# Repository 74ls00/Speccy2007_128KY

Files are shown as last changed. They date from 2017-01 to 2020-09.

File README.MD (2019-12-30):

# Speccy 2007 128K AY PAL SCART 2017

За основу взята единственная на тот момент полная схема 128к от Ljubitel, архив его проекта тут https://github.com/74ls00/Speccy2007_by_Ljubitel

Добавлен кодер PAL и разъём SCART.

Проект в процессе тестирования

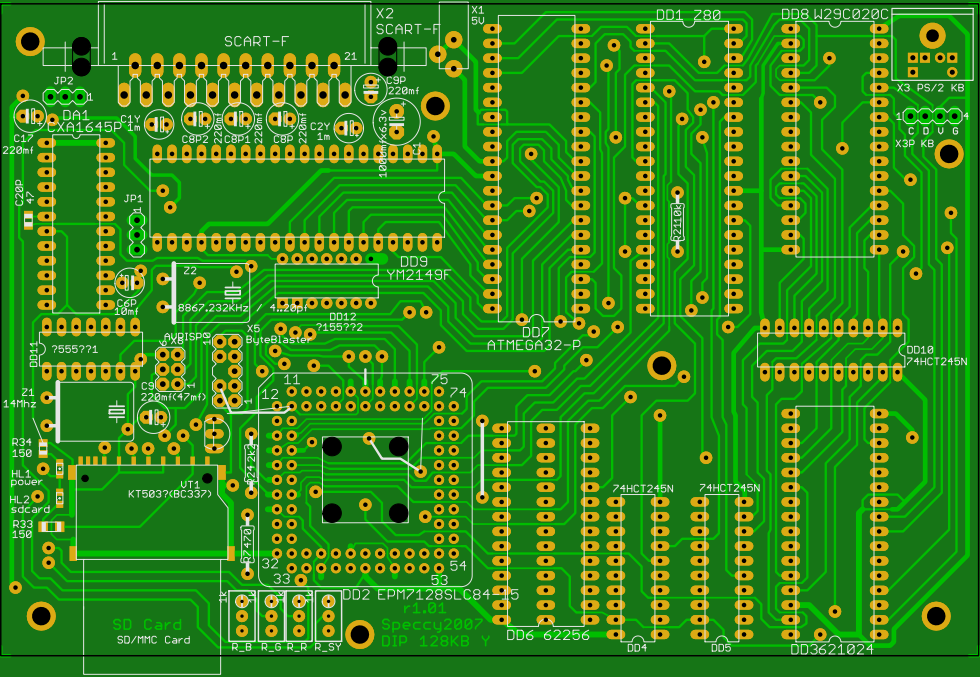
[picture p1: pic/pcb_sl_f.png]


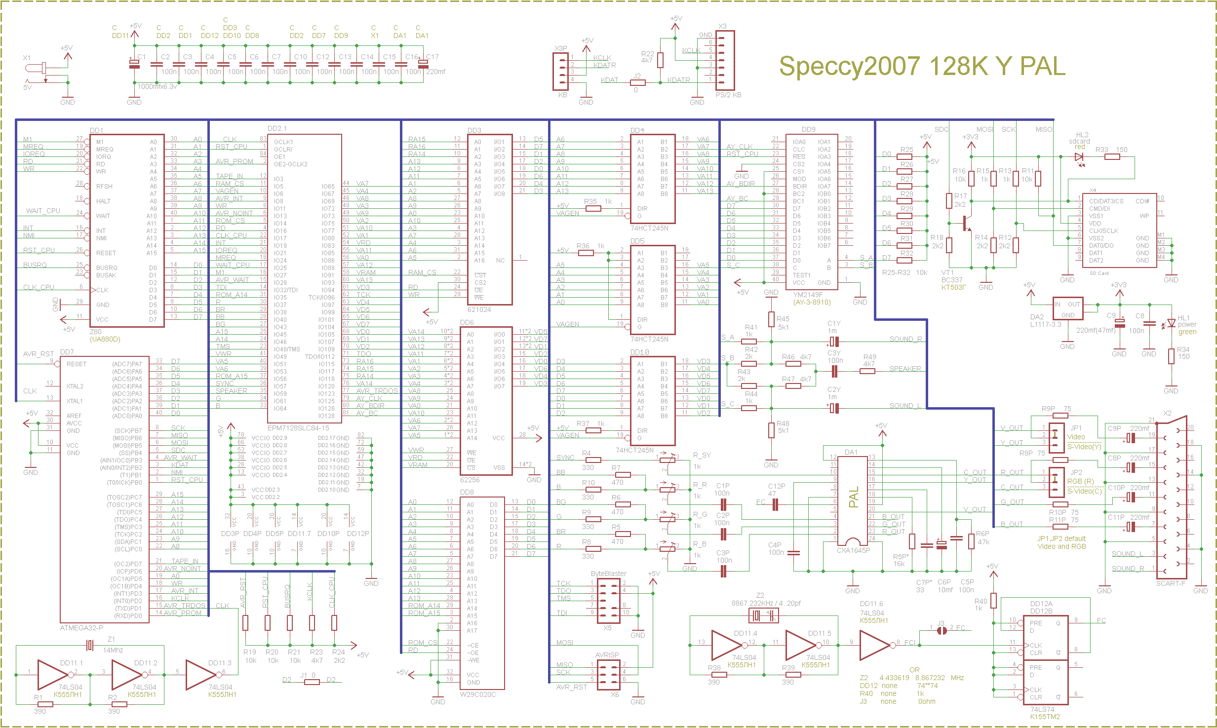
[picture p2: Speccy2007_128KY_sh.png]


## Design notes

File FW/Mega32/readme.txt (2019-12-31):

speccy2007_v106r4_(128+AY+trdos)_src.7z
http://zx-pk.ru/threads/10316-speccy2007-v1-06-(128-ay-trdos).html

Список клавиш
https://zx-pk.ru/threads/12027-speccy2007-sborka-i-naladka.html?p=295229&viewfull=1#post295229

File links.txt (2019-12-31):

Speccy2007 - сборка и наладка
https://zx-pk.ru/threads/12027-speccy2007-sborka-i-naladka.html

Speccy2007 v1.06 (128 + AY + TRDOS)
https://zx-pk.ru/threads/10316-speccy2007-v1-06-(128-ay-trdos).html

Speccy2007 v1.00
https://zx-pk.ru/threads/6679-speccy2007-v1-00.html

Speccy2007 v2.00
теоретическая тема заброшена в 2009
https://zx-pk.ru/threads/9927-speccy2007-v2-00.html

Ссылки на этот гит.
Мой проект 2017
https://github.com/74ls00/Speccy2007_128KY
Авторский проект 2010
https://github.com/74ls00/Speccy2007_by_Ljubitel

Дальнейшее наблюдение за темой "Speccy2007 v1.06 (128 + AY + TRDOS)" начато в 2019.
Вариант с одной микросхемой ОЗУ с.33
прошивка к нему с.34
Модифицированая прошивка с.35, исправление с.36, с.42, (43)

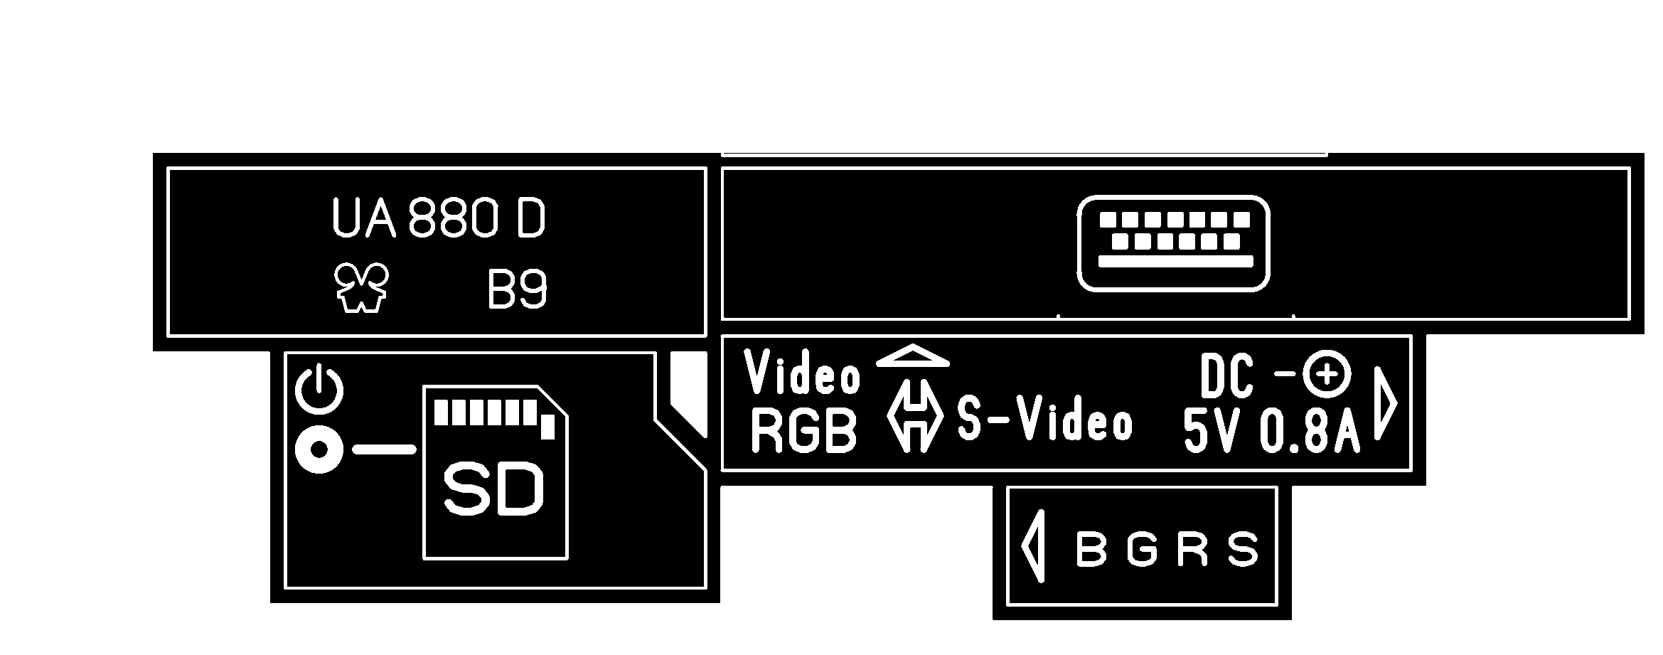
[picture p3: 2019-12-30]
sticker/sticker.png

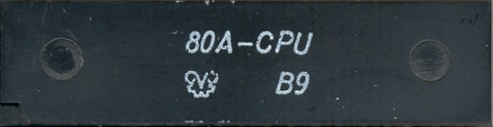
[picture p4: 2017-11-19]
sticker/mme_80a_cpu_b9_cr.bmp

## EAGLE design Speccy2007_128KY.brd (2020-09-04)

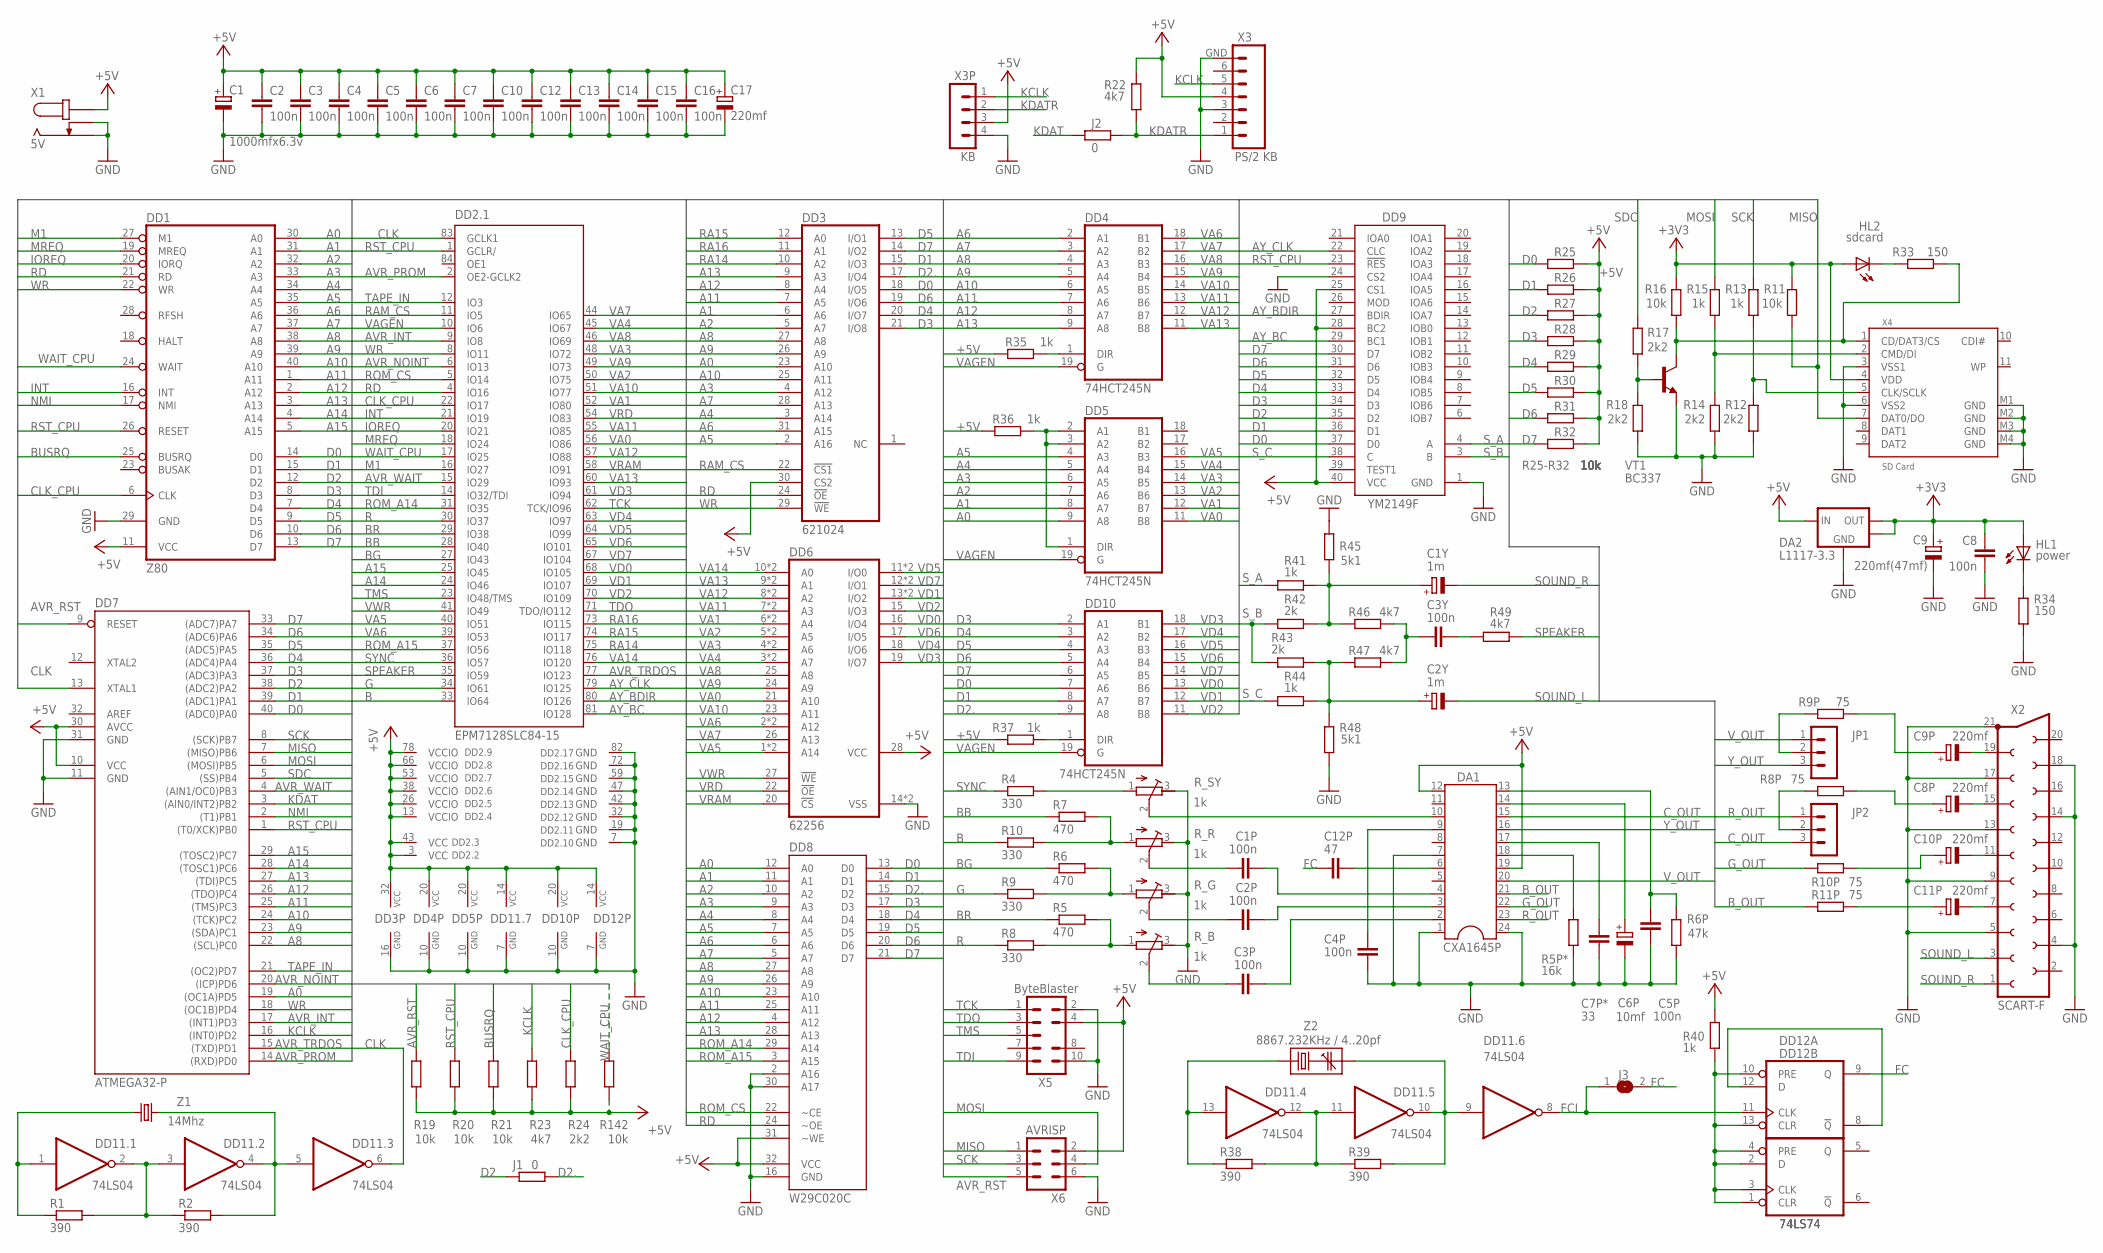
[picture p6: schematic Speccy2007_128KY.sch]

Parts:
C1: 1000mfx6.3v; E3,5-8
C1P, C2, C2P, C3, C3P, C3Y, C4P, C5, C7, C8, C10, C12, C13, C14, C15, C16: 100n; C0805
C1Y, C2Y: 1m; E2,5-5
C4, C5P, C6: 100n; C1206
C6P: 10mf; E2,5-5
C7P*: 33; C1206
C8P, C9P, C10P, C11P, C17: 220mf; E2,5-6
C9: 220mf(47mf); E2,5-6
C12P: 47; C0805
DA1: CXA1645P; DIL24-4
DA2: L1117-3.3; SOT-223
DD1: Z80; DIL40
DD2: EPM7128SLC84-15; PGA-84-B
DD3: 621024; DIL32
DD4, DD5, DD10: 74HCT245N; DIL20
DD6: 62256; DIL28+6
DD7: ATMEGA32-P; DIL40
DD8: W29C020C; DIL32
DD9: YM2149F; DIL40
DD11: 74LS04; DIL14
DD12: 74LS74; DIL14O
HL1: power; SML0805
HL2: sdcard; SML0805
J1: 0; M1206
J2: 0; R1206
J3: SJ
JP1, JP2: MA03-1
R1, R2, R38, R39: 390; R0805
R4, R8, R9, R10: 330; R0805
R5: 470; R0805
R5P*: 16k; M1206
R6: 470; R1206
R6P: 47k; R0805
R7: 470; 0207/10
R8P, R9P, R10P, R11P: 75; R1206
R11, R16, R20, R25, R27, R28, R29, R30, R31, R32: 10k; R0805
R12: 2k2; R1206
R13, R15, R35, R36, R37, R40, R41: 1k; R0805
R14, R17, R18: 2k2; R0805
R19, R26: 10k; M0805
R21, R142: 10k; 0207/10
R22, R47, R49: 4k7; R0805
R23, R46: 4k7; R1206
R24: 2k2; 0207/10
R33: 150; R1206
R34: 150; R0805
R42, R43: 2k; R0805
R44: 1k; R1206
R45: 5k1; R1206
R48: 5k1; R0805
R_B: 1k; RTRIM3296W
R_G: 1k; RTRIM3296W
R_R: 1k; RTRIM3296W
R_SY: 1k; RTRIM3296W
VT1: BC337; TO92-CBE
X1: 5V; POWER3.5
X2: SCART-F
X3: PS/2 KB; MINI-DIN6
X3P: KB; MA04-1
X4: SD Card; SDCMF-10915W010
X5: ByteBlaster; MA05-2
X6: AVRISP; MA03-2
Z1: 14Mhz; HC49U-H
Z2: 8867.232KHz / 4..20pf; HC49U-H

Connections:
+3V3: C8.1, C9.+, DA2.2 (OUT), DA2.4 (OUT'), HL1.A, HL2.A, R11.2, R16.2, X4.4 (VDD)
+5V: C1.+, C2.1, C3.1, C4.1, C5.1, C6.1, C7.1, C10.1, C12.1, C13.1, C14.1, C15.1, C16.1, C17.+, DA1.12, DA1.19, DA2.3 (IN), DD1.11 (VCC), DD2.3 (VCC), DD2.13 (VCCIO), DD2.26 (VCCIO), DD2.38 (VCCIO), DD2.43 (VCC), DD2.53 (VCCIO), DD2.66 (VCCIO), DD2.78 (VCCIO), DD3.30 (CS2), DD3.32 (VCC), DD4.20 (VCC), DD5.20 (VCC), DD6.28 (VCC), DD7.10 (VCC), DD7.30 (AVCC), DD8.31 (~WE), DD8.32 (VCC), DD9.25 (CS1), DD9.28 (BC2), DD9.40 (VCC), DD10.20 (VCC), DD11.14 (VCC), DD12.14 (VCC), R19.1, R20.1, R21.1, R22.2, R23.1, R24.1, R25.2, R26.2, R27.2, R28.2, R29.2, R30.2, R31.2, R32.2, R35.2, R36.2, R37.2, R40.2, R142.1, X1.P$1 (1), X3.4, X3P.3, X5.4, X6.2
A0: DD1.30 (A0), DD3.23 (A10), DD5.9 (A8), DD7.19 ((OC1A)PD5), DD8.12 (A0)
A1: DD1.31 (A1), DD3.6 (A6), DD5.8 (A7), DD8.11 (A1)
A2: DD1.32 (A2), DD3.5 (A7), DD5.7 (A6), DD8.10 (A2)
A3: DD1.33 (A3), DD3.4 (A12), DD5.6 (A5), DD8.9 (A3)
A4: DD1.34 (A4), DD3.3 (A14), DD5.5 (A4), DD8.8 (A4)
A5: DD1.35 (A5), DD3.2 (A16), DD5.4 (A3), DD8.7 (A5)
A6: DD1.36 (A6), DD3.31 (A15), DD4.2 (A1), DD8.6 (A6)
A7: DD1.37 (A7), DD3.28 (A13), DD4.3 (A2), DD8.5 (A7)
A8: DD1.38 (A8), DD3.27 (A8), DD4.4 (A3), DD7.22 ((SCL)PC0), DD8.27 (A8)
A9: DD1.39 (A9), DD3.26 (A9), DD4.5 (A4), DD7.23 ((SDA)PC1), DD8.26 (A9)
A10: DD1.40 (A10), DD3.25 (A11), DD4.6 (A5), DD7.24 ((TCK)PC2), DD8.23 (A10)
A11: DD1.1 (A11), DD3.7 (A5), DD4.7 (A6), DD7.25 ((TMS)PC3), DD8.25 (A11)
A12: DD1.2 (A12), DD3.8 (A4), DD4.8 (A7), DD7.26 ((TDO)PC4), DD8.4 (A12)
A13: DD1.3 (A13), DD3.9 (A3), DD4.9 (A8), DD7.27 ((TDI)PC5), DD8.28 (A13)
A14: DD1.4 (A14), DD2.24 (IO46), DD7.28 ((TOSC1)PC6)
A15: DD1.5 (A15), DD2.25 (IO45), DD7.29 ((TOSC2)PC7)
AVR_INT: DD2.9 (IO8), DD7.17 ((INT1)PD3)
AVR_NOINT: DD2.6 (IO13), DD7.20 ((ICP)PD6)
AVR_PROM: DD2.2 (OE2-GCLK2), DD7.14 ((RXD)PD0)
AVR_RST: DD7.9 (RESET), R19.2, X6.5
AVR_TRDOS: DD2.77 (IO123), DD7.15 ((TXD)PD1)
AVR_WAIT: DD2.15 (IO29), DD7.4 ((AIN1/OC0)PB3)
AY_BC: DD2.81 (IO128), DD9.29 (BC1)
AY_BDIR: DD2.80 (IO126), DD9.27 (BDIR)
AY_CLK: DD2.79 (IO125), DD9.22 (CLC)
B: DD2.33 (IO64), R10.1
BB: DD2.28 (IO40), R7.1
BG: DD2.27 (IO43), R6.1
BR: DD2.29 (IO38), R5.1
BUSRQ: DD1.25 (BUSRQ), R21.2
B_OUT: DA1.21, R11P.1
CDDAT3: R16.1, R33.1, VT1.C, X4.1 (CD/DAT3/CS)
CLK: DD2.83 (GCLK1), DD7.13 (XTAL1), DD11.6 (O)
CLK_CPU: DD1.6 (CLK), DD2.22 (IO17), R24.2
C_OUT: DA1.15, JP2.3
D0: DD1.14 (D0), DD3.18 (I/O5), DD7.40 ((ADC0)PA0), DD8.13 (D0), DD9.37 (D0), DD10.7 (A6), R25.1
D1: DD1.15 (D1), DD3.15 (I/O3), DD7.39 ((ADC1)PA1), DD8.14 (D1), DD9.36 (D1), DD10.8 (A7), R26.1
D2: DD1.12 (D2), DD7.38 ((ADC2)PA2), DD9.35 (D2), J1.1, R27.1
D2.: DD3.17 (I/O4), DD8.15 (D2), DD10.9 (A8), J1.2
D3: DD1.8 (D3), DD3.21 (I/O8), DD7.37 ((ADC3)PA3), DD8.17 (D3), DD9.34 (D3), DD10.2 (A1), R28.1
D4: DD1.7 (D4), DD3.20 (I/O7), DD7.36 ((ADC4)PA4), DD8.18 (D4), DD9.33 (D4), DD10.3 (A2), R29.1
D5: DD1.9 (D5), DD3.13 (I/O1), DD7.35 ((ADC5)PA5), DD8.19 (D5), DD9.32 (D5), DD10.4 (A3), R30.1
D6: DD1.10 (D6), DD3.19 (I/O6), DD7.34 ((ADC6)PA6), DD8.20 (D6), DD9.31 (D6), DD10.5 (A4), R31.1
D7: DD1.13 (D7), DD3.14 (I/O2), DD7.33 ((ADC7)PA7), DD8.21 (D7), DD9.30 (D7), DD10.6 (A5), R32.1
FC: C12P.1, DD12.9 (Q), J3.2
FCI: DD11.8 (O), DD12.11 (CLK), J3.1
G: DD2.34 (IO61), R9.1
GND: C1.-, C2.2, C3.2, C4.2, C4P.1, C5.2, C5P.1, C6.2, C6P.-, C7.2, C7P*.2, C8.2, C9.-, C10.2, C12.2, C13.2, C14.2, C15.2, C16.2, C17.-, DA1.1, DA1.7, DA1.24, DA2.1 (GND), DD1.29 (GND), DD2.7 (GND), DD2.19 (GND), DD2.32 (GND), DD2.42 (GND), DD2.47 (GND), DD2.59 (GND), DD2.72 (GND), DD2.82 (GND), DD3.16 (GND), DD4.10 (GND), DD5.10 (GND), DD6.14 (VSS), DD6.P$14 (VSS), DD7.11 (GND), DD7.31 (GND), DD8.2 (A16), DD8.16 (GND), DD8.30 (A17), DD9.1 (GND), DD9.24 (CS2), DD10.10 (GND), DD11.7 (GND), DD12.7 (GND), R5P*.1, R6P.1, R12.1, R14.1, R18.1, R34.1, R45.2, R48.2, R_B.3 (A), R_G.3 (A), R_R.3 (A), R_SY.3 (A), VT1.E, X1.P$2 (2), X1.P$3 (3), X2.4, X2.5, X2.9, X2.13, X2.14, X2.17, X2.18, X2.21, X3.3, X3.GND (7), X3P.4, X4.3 (VSS1), X4.6 (VSS2), X4.M1 (GND), X4.M2 (GND), X4.M3 (GND), X4.M4 (GND), X5.2, X5.10, X6.6
G_OUT: DA1.22, R10P.1
INT: DD1.16 (INT), DD2.21 (IO19)
IOREQ: DD1.20 (IORQ), DD2.20 (IO21)
KCLK: DD7.16 ((INT0)PD2), R23.2, X3.5, X3P.1
KDAT: DD7.3 ((AIN0/INT2)PB2), J2.1
KDATR: J2.2, R22.1, X3.1, X3P.2
M1: DD1.27 (M1), DD2.16 (IO27)
MISO: DD7.7 ((MISO)PB6), R11.1, X4.7 (DAT0/DO), X6.1
MOSI: DD7.6 ((MOSI)PB5), R15.2, X6.4
MREQ: DD1.19 (MREQ), DD2.18 (IO24)
unnamed: DD11.4 (O), DD11.5 (I), R2.2, Z1.2
unnamed: C3Y.1, R46.2, R47.2
unnamed: C3Y.2, R49.1
unnamed: C1Y.+, R41.2, R42.2, R45.1, R46.1
unnamed: DD11.2 (O), DD11.3 (I), R1.2, R2.1
unnamed: R4.2, R_SY.1 (E)
unnamed: C2Y.+, R43.2, R44.2, R47.1, R48.1
unnamed: R7.2, R10.2, R_R.1 (E)
unnamed: R6.2, R9.2, R_G.1 (E)
unnamed: R5.2, R8.2, R_B.1 (E)
unnamed: C1P.1, R_R.2 (S)
unnamed: DD11.1 (I), R1.1, Z1.1
unnamed: C2P.1, R_G.2 (S)
unnamed: C3P.1, R_B.2 (S)
unnamed: R17.1, R18.2, VT1.B
unnamed: R12.2, R13.1, X4.5 (CLK/SCLK)
unnamed: R14.2, R15.1, X4.2 (CMD/DI)
unnamed: DA1.10, R_SY.2 (S)
unnamed: DD10.1 (DIR), R37.1
unnamed: DD5.1 (DIR), DD5.2 (A1), DD5.3 (A2), R36.1
unnamed: C9P.-, X2.19
unnamed: JP1.2, R9P.1
unnamed: C4P.2, DA1.9
unnamed: C8P.-, X2.15
unnamed: JP2.2, R8P.1
unnamed: C10P.-, X2.11
unnamed: C11P.-, X2.7
unnamed: C10P.+, R10P.2
unnamed: C3P.2, DA1.2
unnamed: C11P.+, R11P.2
unnamed: DD12.8 (!Q), DD12.12 (D)
unnamed: HL1.C, R34.2
unnamed: DD12.1 (CLR), DD12.2 (D), DD12.3 (CLK), DD12.4 (PRE), DD12.10 (PRE), DD12.13 (CLR), R40.1
unnamed: HL2.C, R33.2
unnamed: DD4.1 (DIR), R35.1
unnamed: DD11.11 (I), DD11.12 (O), R38.2, R39.1
unnamed: DD11.9 (I), DD11.10 (O), R39.2, Z2.2
unnamed: DD11.13 (I), R38.1, Z2.1
unnamed: C2P.2, DA1.3
unnamed: C1P.2, DA1.4
unnamed: C9P.+, R9P.2
unnamed: DA1.18, R5P*.2
unnamed: C5P.2, DA1.13, R6P.2
unnamed: C6P.+, DA1.14
unnamed: C8P.+, R8P.2
unnamed: C12P.2, DA1.6
unnamed: C7P*.1, DA1.17
NMI: DD1.17 (NMI), DD7.2 ((T1)PB1)
R: DD2.30 (IO37), R8.1
RA14: DD2.75 (IO118), DD3.10 (A2)
RA15: DD2.74 (IO117), DD3.12 (A0)
RA16: DD2.73 (IO115), DD3.11 (A1)
RAM_CS: DD2.11 (IO5), DD3.22 (!CS1)
RD: DD1.21 (RD), DD2.4 (IO16), DD3.24 (!OE), DD8.24 (~OE)
ROM_A14: DD2.31 (IO35), DD8.29 (A14)
ROM_A15: DD2.37 (IO56), DD8.3 (A15)
ROM_CS: DD2.5 (IO14), DD8.22 (~CE)
RST_CPU: DD1.26 (RESET), DD2.1 (GCLR/), DD7.1 ((T0/XCK)PB0), DD9.23 (!RES), R20.2
R_OUT: DA1.23, JP2.1
SCK: DD7.8 ((SCK)PB7), R13.2, X6.3
SDC: DD7.5 ((SS)PB4), R17.2
SOUND_L: C2Y.-, X2.3
SOUND_R: C1Y.-, X2.1
SPEAKER: DD2.35 (IO59), R49.2
SYNC: DD2.36 (IO57), R4.1
S_A: DD9.4 (A), R41.1
S_B: DD9.3 (B), R42.1, R43.1
S_C: DD9.38 (C), R44.1
TAPE_IN: DD2.12 (IO3), DD7.21 ((OC2)PD7)
TCK: DD2.62 (TCK/IO96), X5.1
TDI: DD2.14 (IO32/TDI), X5.9
TDO: DD2.71 (TDO/IO112), X5.3
TMS: DD2.23 (IO48/TMS), X5.5
VA0: DD2.56 (IO86), DD5.11 (B8), DD6.21 (A10)
VA1: DD2.52 (IO80), DD5.12 (B7), DD6.6 (A4), DD6.P$6 (A4)
VA2: DD2.50 (IO75), DD5.13 (B6), DD6.5 (A5), DD6.P$5 (A5)
VA3: DD2.48 (IO72), DD5.14 (B5), DD6.4 (A6), DD6.P$4 (A6)
VA4: DD2.45 (IO67), DD5.15 (B4), DD6.3 (A7), DD6.P$3 (A7)
VA5: DD2.40 (IO51), DD5.16 (B3), DD6.1 (A14), DD6.P$1 (A14)
VA6: DD2.39 (IO53), DD4.18 (B1), DD6.2 (A12), DD6.P$2 (A12)
VA7: DD2.44 (IO65), DD4.17 (B2), DD6.26 (A13)
VA8: DD2.46 (IO69), DD4.16 (B3), DD6.25 (A8)
VA9: DD2.49 (IO73), DD4.15 (B4), DD6.24 (A9)
VA10: DD2.51 (IO77), DD4.14 (B5), DD6.23 (A11)
VA11: DD2.55 (IO85), DD4.13 (B6), DD6.7 (A3), DD6.P$7 (A3)
VA12: DD2.57 (IO88), DD4.12 (B7), DD6.8 (A2), DD6.P$8 (A2)
VA13: DD2.60 (IO93), DD4.11 (B8), DD6.9 (A1), DD6.P$9 (A1)
VA14: DD2.76 (IO120), DD6.10 (A0), DD6.P$10 (A0)
VAGEN: DD2.10 (IO6), DD4.19 (G), DD5.19 (G), DD10.19 (G)
VD0: DD2.68 (IO105), DD6.16 (I/O4), DD10.13 (B6)
VD1: DD2.69 (IO107), DD6.13 (I/O2), DD6.P$13 (I/O2), DD10.12 (B7)
VD2: DD2.70 (IO109), DD6.15 (I/O3), DD10.11 (B8)
VD3: DD2.61 (IO94), DD6.19 (I/O7), DD10.18 (B1)
VD4: DD2.63 (IO97), DD6.18 (I/O6), DD10.17 (B2)
VD5: DD2.64 (IO99), DD6.11 (I/O0), DD6.P$11 (I/O0), DD10.16 (B3)
VD6: DD2.65 (IO101), DD6.17 (I/O5), DD10.15 (B4)
VD7: DD2.67 (IO104), DD6.12 (I/O1), DD6.P$12 (I/O1), DD10.14 (B5)
VRAM: DD2.58 (IO91), DD6.20 (!CS)
VRD: DD2.54 (IO83), DD6.22 (!OE)
VWR: DD2.41 (IO49), DD6.27 (!WE)
V_OUT: DA1.20, JP1.1
WAIT_CPU: DD1.24 (WAIT), DD2.17 (IO25), R142.2
WR: DD1.22 (WR), DD2.8 (IO11), DD3.29 (!WE), DD7.18 ((OC1B)PD4)
Y_OUT: DA1.16, JP1.3

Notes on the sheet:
R25-R32

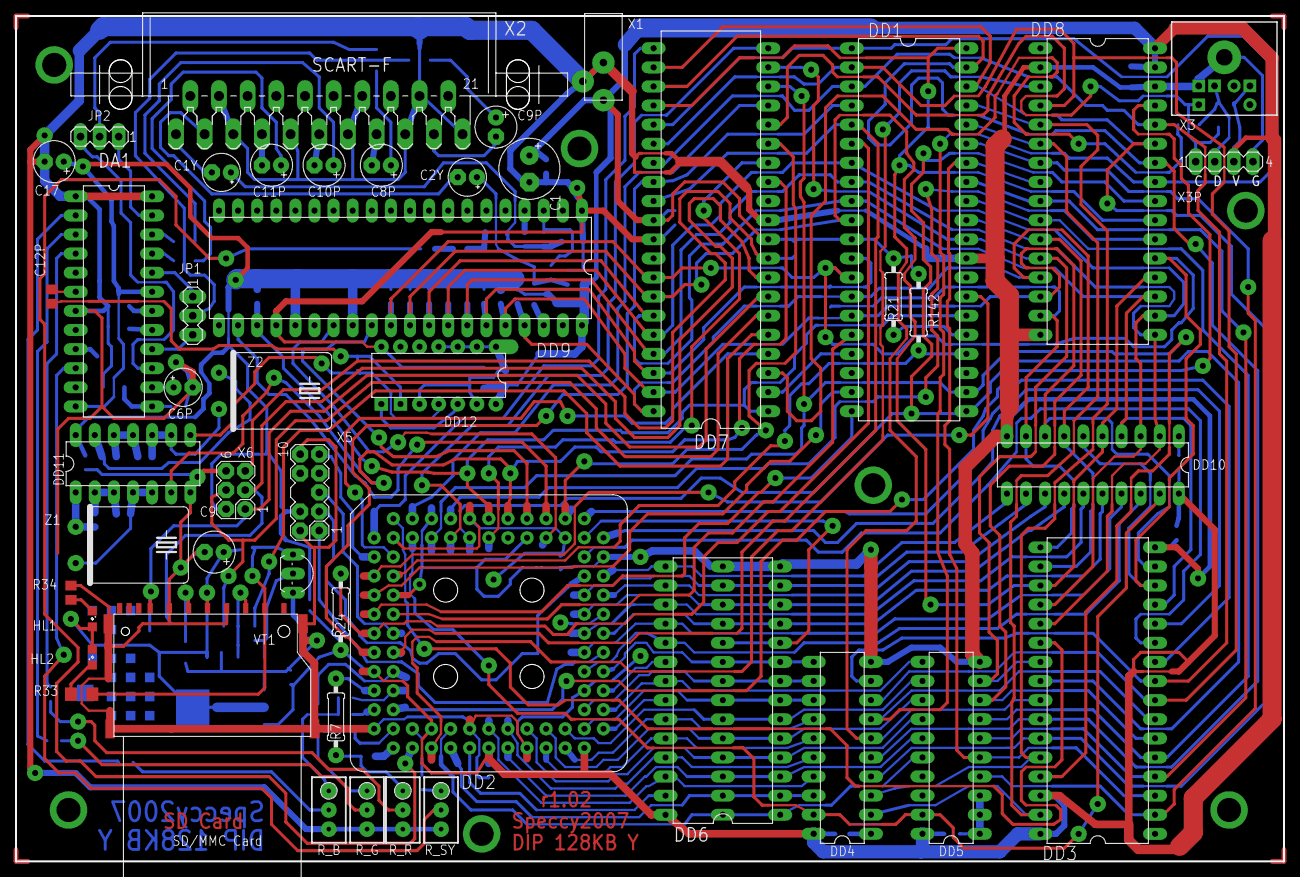
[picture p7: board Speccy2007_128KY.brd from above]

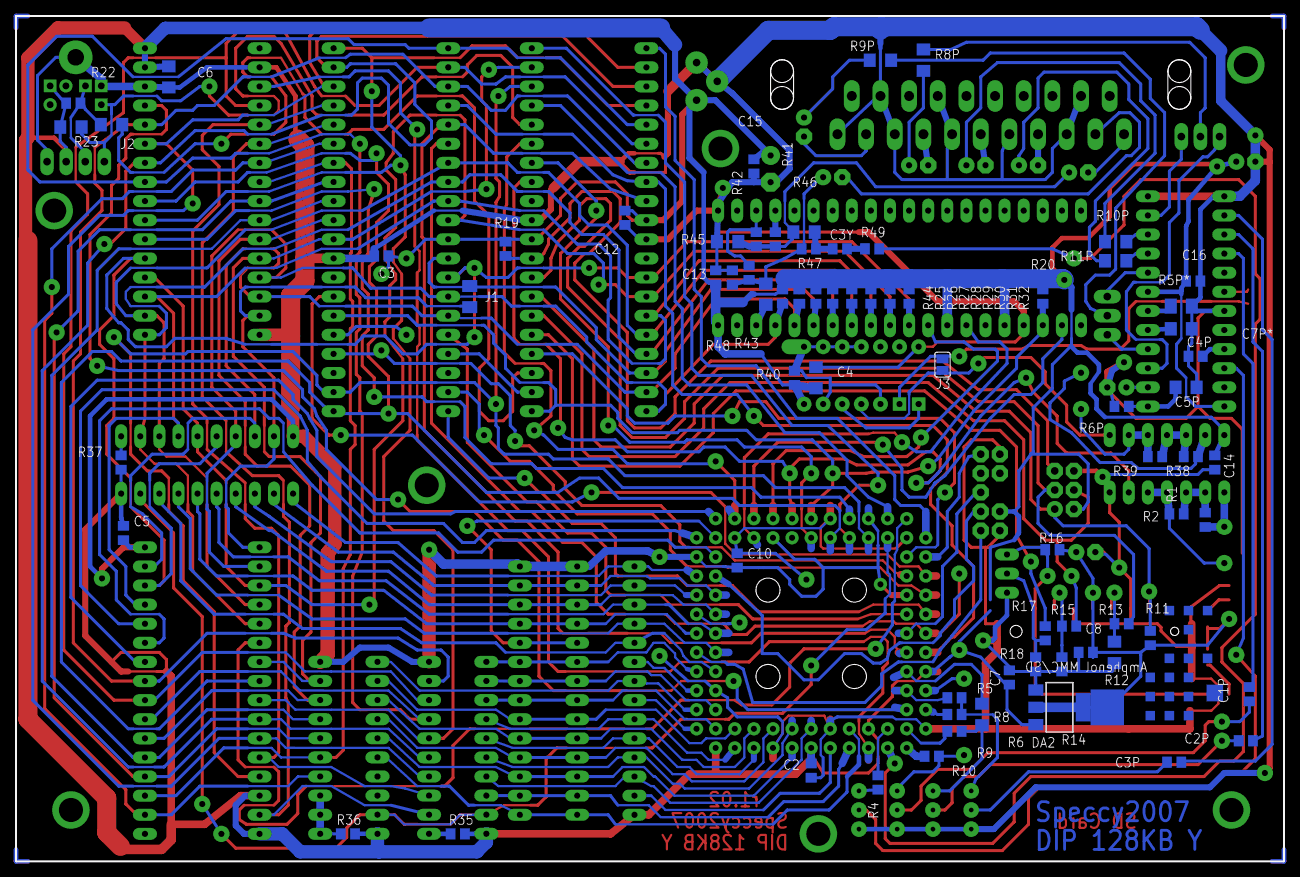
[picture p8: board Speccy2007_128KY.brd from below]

Board: 2 copper layers, 168.6 x 112.4 mm, 121 parts (73 on the bottom side), 164 nets.

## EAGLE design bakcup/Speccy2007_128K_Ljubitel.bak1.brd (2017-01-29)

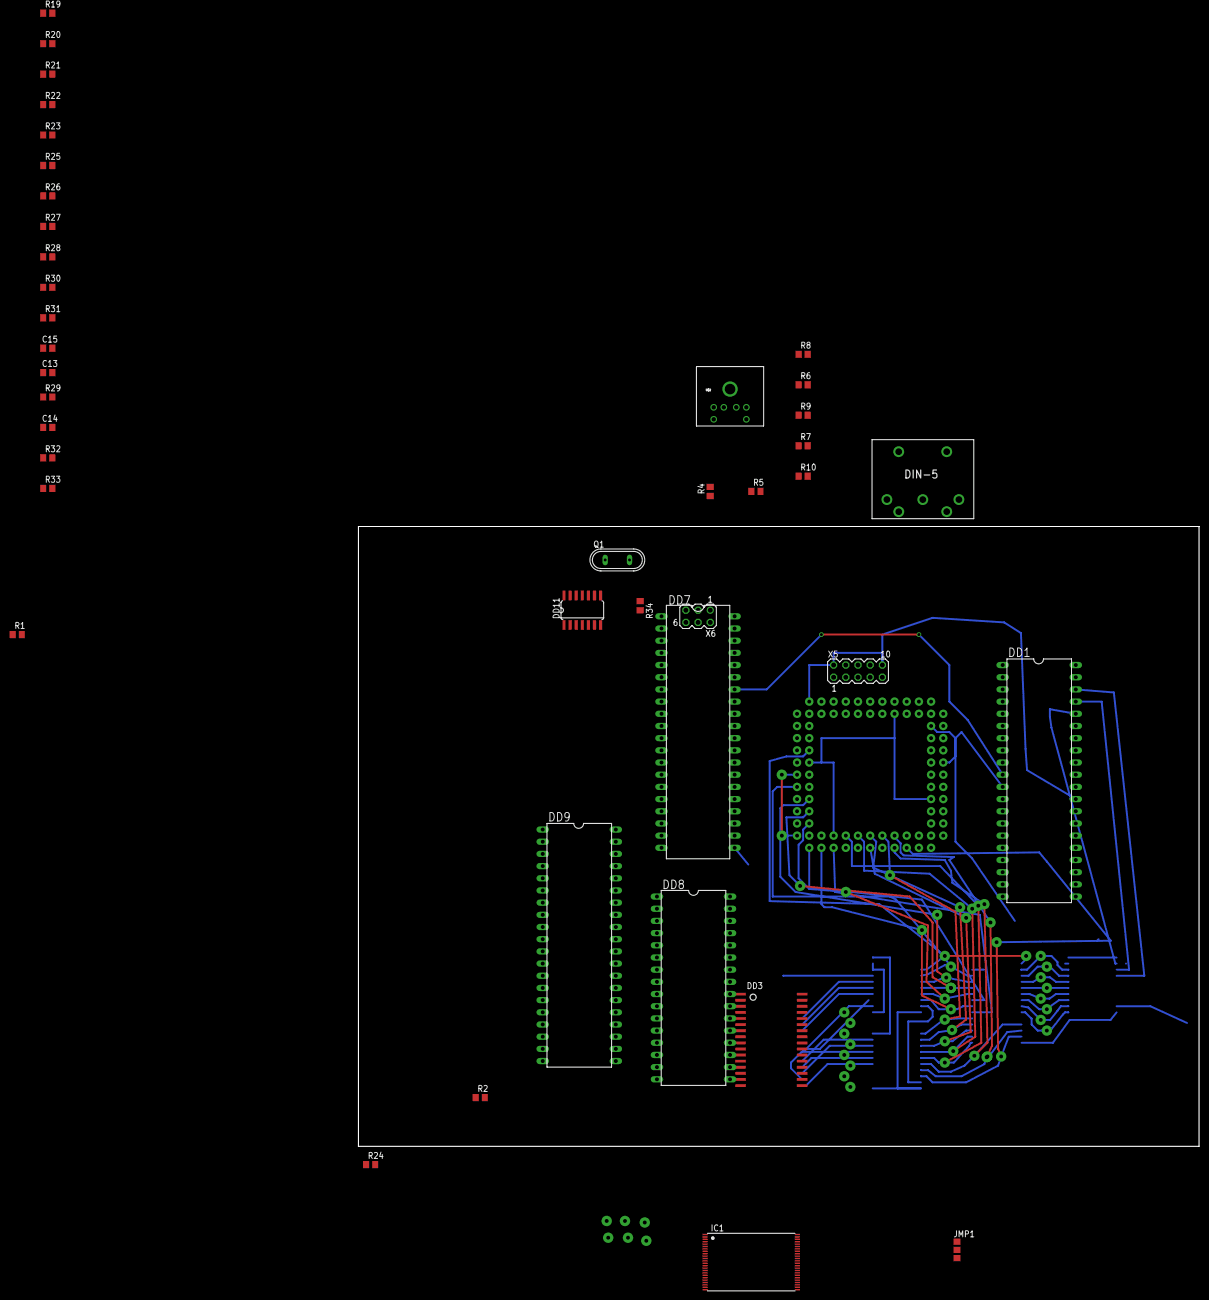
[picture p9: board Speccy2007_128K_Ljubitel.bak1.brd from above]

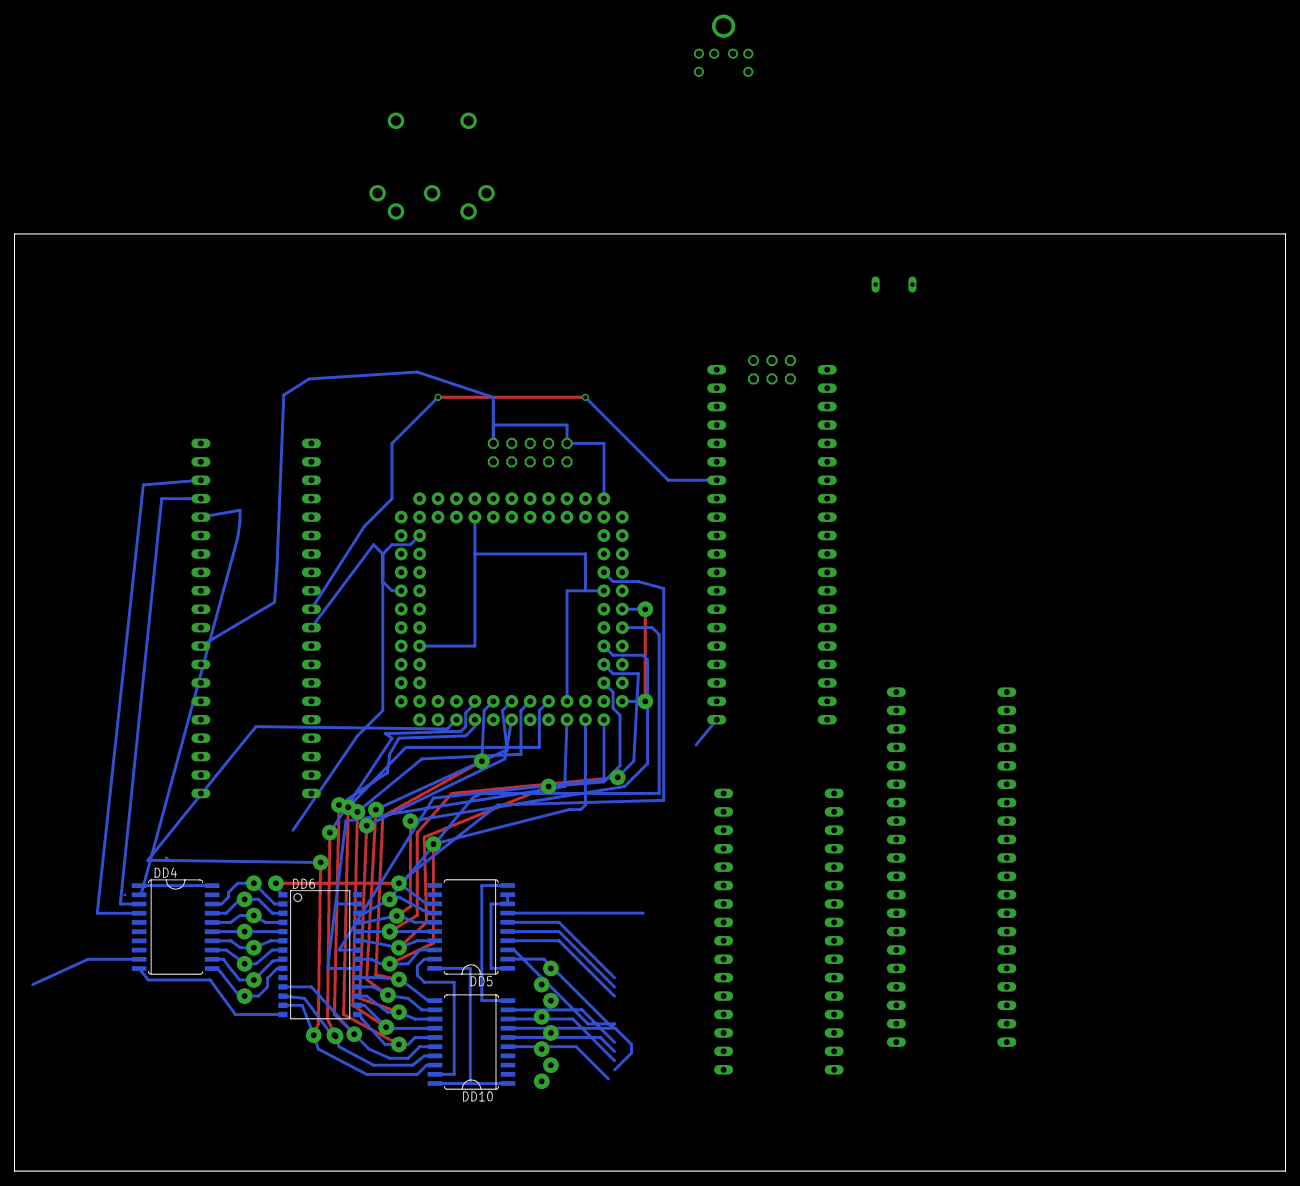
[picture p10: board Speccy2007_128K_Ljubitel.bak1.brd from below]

Board: 2 copper layers, 175.2 x 129.2 mm, 46 parts (4 on the bottom side), 113 nets.

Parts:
C13, C14: 1m; C0805
C15: 0.1; C0805
DD1: Z80; DIL40
DD2: EPM7128-J84; PGA-84
DD3: 621024; SOP32L
DD4, DD5, DD10: 74HCT245DW; SO20W
DD6: 62256; SO28L
DD7: MEGA16-P; DIL40
DD8: W29C020C; DIL32
DD9: YM2149F; DIL40
DD11: 74HC00D; SO14
IC1: SST39LF800A; TSOP48
JMP1: A0R-JMP
Q1: 14Mhz; QS
R1, R22, R23, R30, R31, R33: 4k7; R0805
R2, R24: 2k2; R0805
R4, R8, R9, R10: 330; R0805
R5, R6, R7: 470; R0805
R19, R20, R21: 10k; R0805
R25, R28: 1k; R0805
R26, R27: 2k; R0805
R29, R32: 5k1; R0805
R34: 360; R0805
U$1: MIDI_CONN_FEMALE_SUPPORT; DIN_5_FEMALE_SUPPORT
U$2: MINI-DIN6PTH; MINI-DIN6
X5: ByteBlaster; MA05-2
X6: AVRISP; MA03-2

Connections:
+5V: DD1.11, DD2.3, DD2.13, DD2.26, DD2.38, DD2.43, DD2.53, DD2.66, DD2.78, DD3.32, DD4.1, DD4.20, DD5.1, DD5.8, DD5.9, DD5.20, DD6.28, DD7.10, DD7.30, DD8.31, DD8.32, DD9.25, DD9.28, DD9.40, DD10.1, DD10.20, DD11.14, JMP1.1, R19.1, R20.1, R21.1, R22.1, R23.1, R24.1, X5.4, X6.2
A: DD9.4, R25.1
A0: DD1.30, DD3.23, DD5.2, DD7.19, DD8.12
A1: DD1.31, DD3.25, DD5.3, DD8.11
A2: DD1.32, DD3.26, DD5.4, DD8.10
A3: DD1.33, DD3.27, DD5.5, DD8.9
A4: DD1.34, DD3.28, DD5.6, DD8.8
A5: DD1.35, DD3.4, DD5.7, DD8.7
A6: DD1.36, DD3.12, DD4.2, DD8.6
A7: DD1.37, DD3.11, DD4.3, DD8.5
A8: DD1.38, DD3.10, DD4.4, DD7.22, DD8.27
A9: DD1.39, DD3.9, DD4.5, DD7.23, DD8.26
A10: DD1.40, DD3.8, DD4.6, DD7.24, DD8.23
A11: DD1.1, DD3.7, DD4.7, DD7.25, DD8.25
A12: DD1.2, DD3.6, DD4.8, DD7.26, DD8.4
A13: DD1.3, DD3.5, DD4.9, DD7.27, DD8.28
A14: DD1.4, DD2.24, DD7.28
A15: DD1.5, DD2.25, DD7.29
AVR_INT: DD2.9, DD7.17
AVR_NOINT: DD2.6, DD7.20
AVR_PROM: DD2.2, DD7.14
AVR_RST: DD7.9, R19.2, X6.5
AVR_TRDOS: DD2.77, DD7.15
AVR_WAIT: DD2.15, DD7.4
AY_BC: DD2.81, DD9.29
AY_BDIR: DD2.80, DD9.27
AY_CLK: DD2.79, DD9.22
B: DD2.33, DD9.3, R10.1, R26.1, R27.1
BB: DD2.28, R7.1
BG: DD2.27, R6.1
BR: DD2.29, R5.1
BUSRQ: DD1.25, R21.2
C: DD9.38, R28.1
CLK: DD2.83, DD7.13, DD11.8
CLK_CPU: DD1.6, DD2.22, R24.2
D0: DD1.14, DD3.13, DD7.40, DD8.13, DD9.37, DD10.4
D1: DD1.15, DD3.14, DD7.39, DD8.14, DD9.36, DD10.3
D2: DD1.12, DD3.15, DD7.38, DD8.15, DD9.35, DD10.2
D3: DD1.8, DD3.17, DD7.37, DD8.17, DD9.34, DD10.5
D4: DD1.7, DD3.20, DD7.36, DD8.18, DD9.33, DD10.6
D5: DD1.9, DD3.18, DD7.35, DD8.19, DD9.32, DD10.7
D6: DD1.10, DD3.19, DD7.34, DD8.20, DD9.31, DD10.8
D7: DD1.13, DD3.21, DD7.33, DD8.21, DD9.30, DD10.9
G: DD2.34, R9.1
GND: DD1.29, DD2.7, DD2.19, DD2.32, DD2.42, DD2.47, DD2.59, DD2.72, DD2.82, DD3.16, DD4.10, DD5.10, DD6.14, DD7.11, DD7.31, DD8.2, DD8.16, DD8.30, DD9.1, DD9.24, DD10.10, DD11.7, IC1.27, IC1.46, R2.1, R29.2, R32.2, X5.2, X5.10, X6.6
INT: DD1.16, DD2.21
IOREQ: DD1.20, DD2.20
KCLK: DD7.16, R23.2
KDAT: DD7.3, R22.2
M1: DD1.27, DD2.16
MISO: DD7.7, X6.1
MOSI: DD7.6, X6.4
MREQ: DD1.19, DD2.18
unnamed: DD11.1, DD11.2, Q1.2, R34.1
unnamed: C15.1, R30.2, R31.2
unnamed: C15.2, R33.1
unnamed: C13.1, R25.2, R26.2, R29.1, R30.1
unnamed: DD11.3, DD11.4, DD11.5, R34.2
unnamed: C14.1, R27.2, R28.2, R31.1, R32.1
unnamed: R5.2, R8.2
unnamed: R6.2, R9.2
unnamed: R7.2, R10.2
unnamed: DD11.6, DD11.9, DD11.10, DD11.12, DD11.13, Q1.1
unnamed: DD3.30, JMP1.2
NMI: DD1.17, DD7.2
R: DD2.30, R8.1
RAM_A14: DD2.75, DD3.3
RAM_A15: DD2.74, DD3.31
RAM_A16: DD2.73, DD3.2
RAM_CS: DD2.11, DD3.22
RD: DD1.21, DD2.4, DD3.24, DD8.24
ROM_A14: DD2.31, DD8.29
ROM_A15: DD2.37, DD8.3
ROM_CS: DD2.5, DD8.22
RST_CPU: DD1.26, DD2.1, DD7.1, DD9.23, R20.2
SCK: DD7.8, X6.3
SOUND_L: C14.2, R1.1, R2.2
SPEAKER: DD2.35, R1.2, R33.2
SYNC: DD2.36, R4.1
TAPE_IN: DD2.12, DD7.21
TCK: DD2.62, X5.1
TDI: DD2.14, X5.9
TDO: DD2.71, X5.3
TMS: DD2.23, X5.5
VA0: DD2.56, DD5.18, DD6.21
VA1: DD2.52, DD5.17, DD6.23
VA2: DD2.50, DD5.16, DD6.24
VA3: DD2.48, DD5.15, DD6.25
VA4: DD2.45, DD5.14, DD6.26
VA5: DD2.40, DD5.13, DD6.1
VA6: DD2.39, DD4.18, DD6.2
VA7: DD2.44, DD4.17, DD6.3
VA8: DD2.46, DD4.16, DD6.4
VA9: DD2.49, DD4.15, DD6.5
VA10: DD2.51, DD4.14, DD6.6
VA11: DD2.55, DD4.13, DD6.7
VA12: DD2.57, DD4.12, DD6.8
VA13: DD2.60, DD4.11, DD6.9
VA14: DD2.76, DD6.10
VAGEN: DD2.10, DD4.19, DD5.19, DD10.19
VD0: DD2.68, DD6.11, DD10.16
VD1: DD2.69, DD6.12, DD10.17
VD2: DD2.70, DD6.13, DD10.18
VD3: DD2.61, DD6.15, DD10.15
VD4: DD2.63, DD6.16, DD10.14
VD5: DD2.64, DD6.17, DD10.13
VD6: DD2.65, DD6.18, DD10.12
VD7: DD2.67, DD6.19, DD10.11
VRAM: DD2.58, DD6.20
VRD: DD2.54, DD6.22
VWR: DD2.41, DD6.27
WAIT_CPU: DD1.24, DD2.17
WR: DD1.22, DD2.8, DD3.29, DD7.18

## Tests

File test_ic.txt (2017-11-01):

В сборке использованы и проверены микросхемы.

Схема сделана теоретически под любые микросхемы мелкой логики. Генератор запускается на любых сериях, неиспользуемые входы подтянуты к питанию через резистор 1к.

DD1     UA880D         выпаяна давно из компьютера "Мастер"

DD3     HM628128ALP-7   с ebay, вродебы работает нормально. Проблемы в bs, возможно и не долно работать
                        http://zx-pk.ru/threads/26092-eshchjo-odin-klon-battle-city-na-zx/page22.html
        UT621024PC-70LL с chipdip, есть проблемы в игре tujad, возможно нехватка питания.
		
DD4,DD5 DM74LS245N     выпаяны из какойто офисной техники вроде монитора или копира.
DD6     Em51256B-20PV  узкая микросхема от кэша старого компьютера.
DD8     W29C020-12     от BIOS .
DD10    SN74ALS245AN   тоже из какойто офисной техники.
DD11    К555ЛН1  проверялись 1533, результат тотже.
DD12    К155ТМ2  поставил что не жалко. К555 и К1533 работают также, и наверно следовало поставить их как более экономичные.

Аналогов нет или это не влияет на стабильность работы.
DD2  EPM7128SLC84-15
DD7  ATMEGA32-PU
DD9  YM2149F
DA1  CXA1645P        разведено только под неё. Под универсальную плату вместе с CXA2075 не было места.
DA2  LD1117ADT33TR   попался в DPAK, но вполне впаялся. Хотя плата изначально делалась под SOT-223, но как оказалось в компьютерах на 3,3в не встречаются, там только на 4в.

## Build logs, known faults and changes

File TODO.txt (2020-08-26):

"Не забываем вешать 24 вывод Z80 на +5, через 10кОм."
возможно это о z44 .
https://zx-pk.ru/threads/10316-speccy2007-v1-06-(128-ay-trdos)/page43.html

петля +5в около vt1
убрать дорожку

светодиод обращения к SD
подключить через транзистор для стабилизации яркости

изменить разводку питания у кодера.
питание пустить через конденсатор.
отделить + питание кодера от основного.

разъём питания не очень качественный. на стабильность не влияет, но проблемы в изображении при плохом контакте. возможно конденсатор поможет.

записать в пзу несколько версий и добавить переключатель

добавить подстроечный конденсатор последовательно кварцу кодера.
в библиотеку добавил, но места на плате не нашлось
----
пал кодер

генератор через 2,2к 47пф
http://zx-pk.ru/threads/10355-sobral-pal-koder/page5.html

вариант1. добавить конденсатор последовательно тактам

вариант2. такт через 1,5к. 6вх через 10пф корпус

33пф к 17 ноге

ссылки 17

12мкг ?
http://www.sega-16.com/forum/showthread.php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*

68мкг 28п 
http://www.neo-geo.com/forums/showthread.php?124538-CXA1645-and-bad-CVBS-output

40пф 100мкг
https://www.google.ru/url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

https://www.retrogaming.com.ar/forum/viewtopic.php?f=4&t=11006&start=140

----
=разъём питания слишком далеко

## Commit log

2017-02-01 lbr bak
    [Speccy2007_128K_Ljubitel.brd, Speccy2007_128K_Ljubitel.sch]
2017-10-19 fix pal 1
    [Speccy2007_128K_Ljubitel.brd, Speccy2007_128K_Ljubitel.sch]
2017-10-26 +pic rm
    [Speccy2007_128KY.brd]

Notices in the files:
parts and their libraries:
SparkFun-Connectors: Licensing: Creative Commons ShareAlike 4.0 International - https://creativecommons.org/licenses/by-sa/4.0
